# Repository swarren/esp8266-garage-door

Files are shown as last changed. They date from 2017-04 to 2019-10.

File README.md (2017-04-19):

# ESP8266 Internet Garage Door Opener

This repo contains all the design files relate to the ESP8266-based garage
door opener project I recently created. My basic requirements were:

- Be functonal and deployed as quickly as possible, rather than being as clean
and well-engineered as possible.

- Not interfere with the electronics of my existing manual-switch-triggered
opener.

Quick list of features/parts:

- ESP8266 WiFi SoC for the Internet connection. NodeMCU board.

- Arduino-based software stack.

- HTTP/HTML-based user interface.

- WiFi credentials entered at "run-time" using a web browser and saved to
flash, rather than being hard-coded into the application code.

- PCB created in Kicad to mount the ESP8266 and connectors.

- Standalone commercial relay board to trigger the door opener.

- HC-SR04 sensors used to detect whether the door is open or closed.

- HC-SR04 wall mounts designed using OpenSCAD and 3D-printed.

Look on my blog at http://rabbithole.wwwdotorg.org for more details.

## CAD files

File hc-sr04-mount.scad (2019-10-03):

/*
 * Copyright (c) 2017, Stephen Warren
 *
 * Permission is hereby granted, free of charge, to any person obtaining a
 * copy of this software and associated documentation files (the "Software"),
 * to deal in the Software without restriction, including without limitation
 * the rights to use, copy, modify, merge, publish, distribute, sublicense,
 * and/or sell copies of the Software, and to permit persons to whom the
 * Software is furnished to do so, subject to the following conditions:
 *
 * The above copyright notice and this permission notice shall be included in
 * all copies or substantial portions of the Software.
 *
 * THE SOFTWARE IS PROVIDED "AS IS", WITHOUT WARRANTY OF ANY KIND, EXPRESS OR
 * IMPLIED, INCLUDING BUT NOT LIMITED TO THE WARRANTIES OF MERCHANTABILITY,
 * FITNESS FOR A PARTICULAR PURPOSE AND NONINFRINGEMENT.  IN NO EVENT SHALL
 * THE AUTHORS OR COPYRIGHT HOLDERS BE LIABLE FOR ANY CLAIM, DAMAGES OR OTHER
 * LIABILITY, WHETHER IN AN ACTION OF CONTRACT, TORT OR OTHERWISE, ARISING
 * FROM, OUT OF OR IN CONNECTION WITH THE SOFTWARE OR THE USE OR OTHER
 * DEALINGS IN THE SOFTWARE.
 */

$fn = 30;

pcb_w = 45 + 1.5;
pcb_h = 20 + 2;
wall_thick = 3;
horn_r = 15.75 / 2;
horn_r_slop = 0.75;
horn_space = 41.5 - (2 * horn_r);
supp_h = 3.5;
supp_l = 7;
mount_depth = wall_thick + supp_h + 9;
flange_l = 10 + wall_thick;
clip_thick = 2;
clip_interior = 9.5;
clip_wide = 9;
clip_depth = 14;

module corner_dist(w, h) {
    translate([-w / 2, -h / 2, 0])
        rotate(0) children();
    translate([-w / 2,  h / 2, 0])
        rotate(270) children();
    translate([ w / 2, -h / 2, 0])
        rotate(90) children();
    translate([ w / 2,  h / 2, 0])
        rotate(180) children();
}

module hc_sr04_mount() {
    // Front face plate, with cut-outs for horns
    base_w = pcb_w + (2 * wall_thick);
    base_h = pcb_h;
    difference() {
        cube([base_w, base_h, wall_thick], center=true);
        translate([-horn_space / 2, 0, 0])
            cylinder(r=horn_r + horn_r_slop, h=(2 * wall_thick), center=true);
        translate([ horn_space / 2, 0, 0])
            cylinder(r=horn_r + horn_r_slop, h=(2 * wall_thick), center=true);
    }

    // Side walls
    wall_x_xlat = (base_w - wall_thick) / 2;
    translate([-wall_x_xlat, 0, (mount_depth - wall_thick) / 2])
        cube([wall_thick, pcb_h, mount_depth], center=true);
    translate([ wall_x_xlat, 0, (mount_depth - wall_thick) / 2])
        cube([wall_thick, pcb_h, mount_depth], center=true);

    // Corner supports
    corner_dist(w=pcb_w, h=pcb_h) {
        translate([0, 0, wall_thick / 2])
            linear_extrude(height=supp_h)
            polygon([[0, 0], [supp_l, 0], [0, supp_l]]);
    }
}

module hc_sr04_flange_a() {
    translate([0, 0, (mount_depth - wall_thick) / 2])
        cube([wall_thick, pcb_h, mount_depth], center=true);
    translate([(flange_l - wall_thick) / 2, 0, 0])
        cube([flange_l, pcb_h, wall_thick], center=true);
}

module hc_sr04_flange_b() {
    translate([0, 0, (mount_depth - wall_thick) / 2])
        cube([wall_thick, pcb_h, mount_depth], center=true);
    translate([(flange_l - wall_thick) / 2, (pcb_h - wall_thick) / 2, (mount_depth - wall_thick)/ 2])
        cube([flange_l, wall_thick, mount_depth], center=true);
}

module hc_sr04_flange_clip() {
    cube([clip_thick, clip_depth + clip_thick, clip_wide], center=true);
    translate([clip_interior + clip_thick, 0, 0])
        cube([clip_thick, clip_depth + clip_thick, clip_wide], center=true);
    translate([(clip_interior + clip_thick) / 2, clip_depth / 2, 0])
        cube([clip_interior + (2 * clip_thick), clip_thick, clip_wide], center=true);
}

hc_sr04_mount();

translate([ ((pcb_w / 2) + (4 * wall_thick)), 0, 0]) hc_sr04_flange_a();
//translate([-((pcb_w / 2) + (4 * wall_thick)), 0, 0]) rotate(180) hc_sr04_flange_a();

//translate([ ((pcb_w / 2) + (4 * wall_thick)), 0, 0]) hc_sr04_flange_b();
translate([-((pcb_w / 2) + (4 * wall_thick)), 0, 0]) rotate(180) hc_sr04_flange_b();

translate([0, -25, 0]) hc_sr04_flange_clip();

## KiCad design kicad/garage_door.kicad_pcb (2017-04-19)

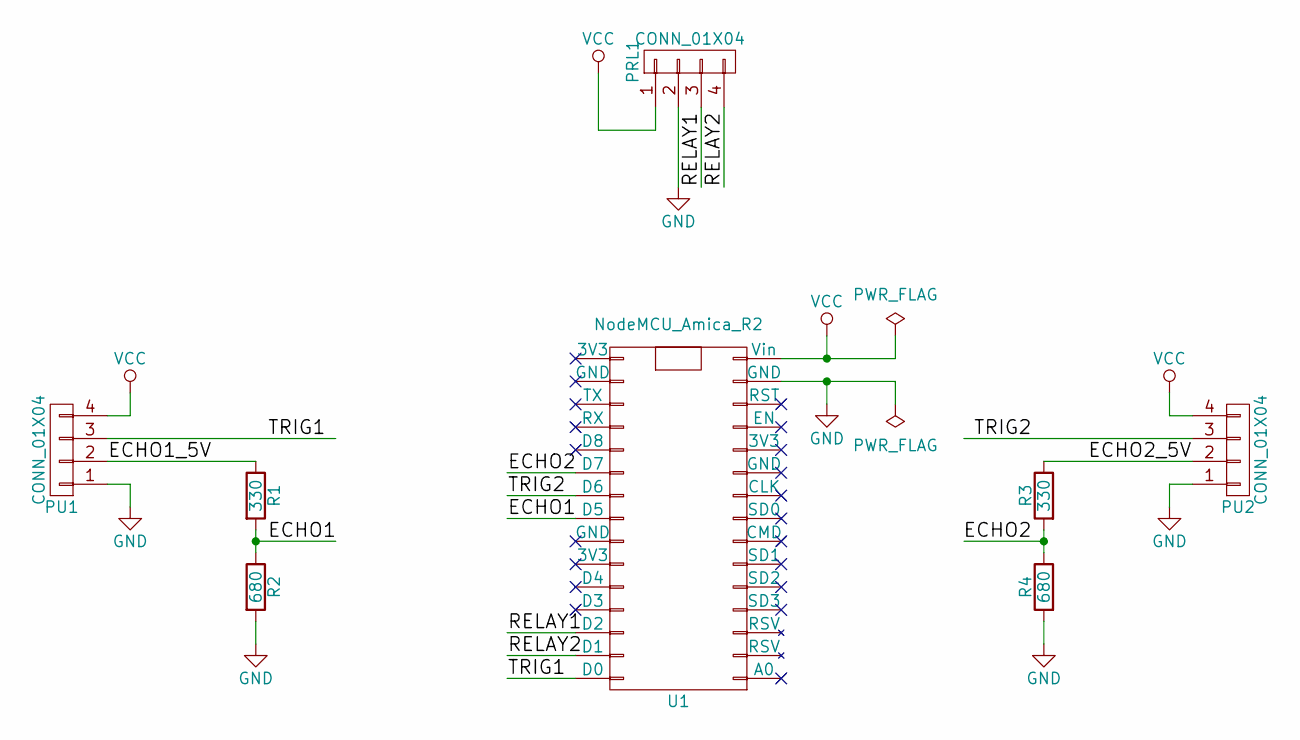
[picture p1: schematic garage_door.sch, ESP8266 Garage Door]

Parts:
PRL1: CONN_01X04; Pin_Header_Angled_1x04_Pitch2.54mm
PU1, PU2: CONN_01X04; Pin_Header_Angled_1x04_Pitch2.54mm
R1, R3: 330; R_Axial_DIN0207_L6.3mm_D2.5mm_P10.16mm_Horizontal
R2, R4: 680; R_Axial_DIN0207_L6.3mm_D2.5mm_P10.16mm_Horizontal
U1: NodeMCU_Amica_R2

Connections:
/ECHO1: R1.2, R2.1, U1.23 (D5)
/ECHO1_5V: PU1.2, R1.1
/ECHO2: R3.2, R4.1, U1.21 (D7)
/ECHO2_5V: PU2.2, R3.1
/RELAY1: PRL1.3, U1.28 (D2)
/RELAY2: PRL1.4, U1.29 (D1)
/TRIG1: PU1.3, U1.30 (D0)
/TRIG2: PU2.3, U1.22 (D6)
GND: PRL1.2, PU1.1, PU2.1, R2.2, R4.2, U1.14 (GND)
VCC: PRL1.1, PU1.4, PU2.4, U1.15 (Vin)

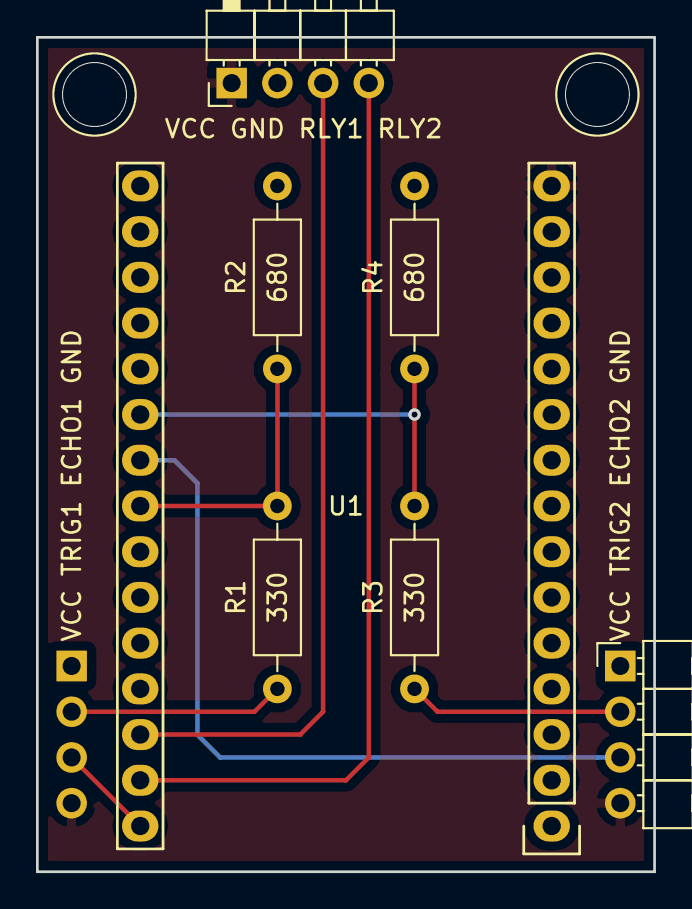
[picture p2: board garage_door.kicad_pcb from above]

Board: 2 copper layers, 34.3 x 46.4 mm, 8 parts (1 on the bottom side), 10 nets.

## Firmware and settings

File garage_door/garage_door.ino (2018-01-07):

/*
 * Copyright (c) 2017, Stephen Warren
 *
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
 * THE SOFTWARE IS PROVIDED "AS IS", WITHOUT WARRANTY OF ANY KIND, EXPRESS OR
 * IMPLIED, INCLUDING BUT NOT LIMITED TO THE WARRANTIES OF MERCHANTABILITY,
 * FITNESS FOR A PARTICULAR PURPOSE AND NONINFRINGEMENT.  IN NO EVENT SHALL
 * THE AUTHORS OR COPYRIGHT HOLDERS BE LIABLE FOR ANY CLAIM, DAMAGES OR OTHER
 * LIABILITY, WHETHER IN AN ACTION OF CONTRACT, TORT OR OTHERWISE, ARISING
 * FROM, OUT OF OR IN CONNECTION WITH THE SOFTWARE OR THE USE OR OTHER
 * DEALINGS IN THE SOFTWARE.
 */
 
#include <math.h>
#include <FS.h>
#include <ESP8266HTTPUpdateServer.h>
#include <ESP8266mDNS.h>
#include <ESP8266LLMNR.h>
#include <ESP8266WebServer.h>
#include <ESP8266WiFi.h>
#include "ESPAsyncTCP.h"

// Development on Adafruit Huzzah
#if 1
#define DEVID "-dev"
#define PIN_BTN 0
#if 1
#define DOOR0_NAME "Dev Door"
#define PIN_DOOR_0 5
#define PIN_ULTRA_TRIG_0 16
#define PIN_ULTRA_ECHO_0 4
#endif
#if 1
#define DOOR1_NAME "Second Door"
#define PIN_DOOR_1 14
#define PIN_ULTRA_TRIG_1 12
#define PIN_ULTRA_ECHO_1 13
#endif
#endif

// Production for main garage on NodeMCU; rev 1 PCB
#if 0
#define DEVID "-main"
#define PIN_BTN 0
#define DOOR0_NAME "Stephen's Door"
#define PIN_DOOR_0 16
#define PIN_ULTRA_TRIG_0 5
#define PIN_ULTRA_ECHO_0 4
#define DOOR1_NAME "Tina's Door"
#define PIN_DOOR_1 14
#define PIN_ULTRA_TRIG_1 12
#define PIN_ULTRA_ECHO_1 13
#endif

// Production for main garage on NodeMCU; rev 2 PCB
#if 0
#define DEVID "-main"
#define PIN_BTN 0
#define DOOR0_NAME "Stephen's Door"
#define PIN_DOOR_0 4
#define PIN_ULTRA_TRIG_0 16
#define PIN_ULTRA_ECHO_0 14
#define DOOR1_NAME "Tina's Door"
#define PIN_DOOR_1 5
#define PIN_ULTRA_TRIG_1 12
#define PIN_ULTRA_ECHO_1 13
#endif

// Production for third garage on NodeMCU; rev 1 PCB (2nd door pins)
#if 0
#define DEVID "-third"
#define PIN_BTN 0
#define DOOR0_NAME "Third Garage"
#define PIN_DOOR_0 14
#define PIN_ULTRA_TRIG_0 12
#define PIN_ULTRA_ECHO_0 13
#define SHORT_ECHO
#endif

#ifdef SHORT_ECHO
#define CLOSED_MIN_ECHO_TIME 500 /* us */
#else
#define CLOSED_MIN_ECHO_TIME \
  (1000000 /* s->us */ * 2 /* there and back */ * 0.3 /* meters */ / \
    343 /* sound_speed_meters_per_sec */)
#endif

#if defined(PIN_ULTRA_TRIG_0) || defined(PIN_ULTRA_TRIG_1)
#define DEBUG_ULTRA 0

class UltraEcho {
public:
  UltraEcho(int pin) :
    m_pin(pin),
    m_wait_for_echo_start(true)
  {
  }

  void pre_trigger(void) {
    m_wait_for_echo_start = true;
  }

  bool is_closed(void) {
    return __builtin_popcount(m_closed_hist & 0xff) >= 6;
  }

  String history_string(void) {
    int hist_bits = sizeof(m_closed_hist) * 8;
    char s[hist_bits + 1];
    for (int i = 0; i < hist_bits; i++)
      s[i] = (m_closed_hist & (1ULL << (hist_bits - i - 1))) ? '*' : '-';
    s[hist_bits] = 0;
    return s;
  }

  void isr_echo() {
    unsigned long t = micros();
    int val = digitalRead(m_pin);
#if DEBUG_ULTRA
    Serial.printf("Echo pin %d val %d waiting %d at %lu\n", m_pin, val, (int)m_wait_for_echo_start, t);
#endif
    if (m_wait_for_echo_start && val) {
#if DEBUG_ULTRA
      Serial.printf("Echo starts...\n");
#endif
      m_ts_echo_start = t;
      m_wait_for_echo_start = false;
    } else if (!m_wait_for_echo_start && !val) {
#if DEBUG_ULTRA
      Serial.printf("Echo done...\n");
#endif
      m_echo_time = t - m_ts_echo_start;
#if DEBUG_ULTRA
      Serial.printf("Echo pin %d time %d us\n", m_pin, m_echo_time);
#endif
      bool closed = (m_echo_time < CLOSED_MIN_ECHO_TIME);
#if DEBUG_ULTRA
      Serial.printf("Closed? %d\n", (int)closed);
#endif
      m_closed_hist <<= 1;
      m_closed_hist |= !!closed;
#if DEBUG_ULTRA
      Serial.printf("Closed hist: 0x%x ?%d\n", m_closed_hist, !!is_closed());
#endif
    }
  }

private:
  int m_pin;
  bool m_wait_for_echo_start;
  unsigned long m_ts_echo_start;
  unsigned long m_echo_time;
  unsigned int m_closed_hist;
};
#endif

enum RelayControllerState {
  RC_STATE_IDLE,
  RC_STATE_HIGH_TIMER,
  RC_STATE_LOW_TIMER,
};

class RelayController {
public:
  RelayController(int pin) :
    m_pin(pin),
    m_trig_count(0),
    m_state(RC_STATE_IDLE),
    m_state_start(0) {
  }

  void iter() {
    switch (m_state) {
    case RC_STATE_HIGH_TIMER:
      if ((millis() - m_state_start) < 500)
        break;
      m_state = RC_STATE_LOW_TIMER;
      m_state_start = millis();
      digitalWrite(m_pin, LOW);
      break;
    case RC_STATE_LOW_TIMER:
      if ((millis() - m_state_start) < 500)
        break;
      m_state = RC_STATE_IDLE;
      // deliberate fall-through
    case RC_STATE_IDLE:
    default:
      if (!m_trig_count)
        break;
      m_trig_count--;
      m_state = RC_STATE_HIGH_TIMER;
      m_state_start = millis();
      digitalWrite(m_pin, HIGH);
      break;
    }
  }

  void trigger() {
    m_trig_count++;
  }

private:
  int m_pin;
  int m_trig_count;
  enum RelayControllerState m_state;
  unsigned long m_state_start;
};

#define DEBUG_SMTP 1

enum SMTPClientState {
  SMTP_STATE_IDLE,
  SMTP_STATE_WAIT_CONNECT,
  SMTP_STATE_WAIT_SIGNON,
  SMTP_STATE_WAIT_FEATURES,
  SMTP_STATE_WAIT_MAIL_FROM_OK,
  SMTP_STATE_WAIT_RCPT_TO_OK,
  SMTP_STATE_WAIT_DATA_RESPONSE,
  SMTP_STATE_WAIT_END_DATA_RESPONSE,
  SMTP_STATE_WAIT_QUIT_RESPONSE,
  SMTP_STATE_WAIT_CLOSED,
};

class LineBuf {
public:
  LineBuf(void) : m_filled(0) {
  }

  void clear(void) {
    m_filled = 0;
  }

  size_t append(void *data, size_t len) {
    size_t space = sizeof(m_data) - m_filled - 1;
    size_t consumed = (space < len) ? space : len;
    memcpy(&m_data[m_filled], data, consumed);
    m_filled += consumed;
    m_data[m_filled] = '\0';
    return consumed;
  }

  char *get_line(size_t *token) {
    char *eol = strstr(m_data, "\r\n");
    if (!eol) {
      *token = 0;
      return NULL;
    }
    *eol = '\0';
    *token = eol - m_data + 2;
#if DEBUG_SMTP
    Serial.printf("SMTP << %s\n", m_data);
#endif
    return m_data;
  }

  void consume_line(size_t token) {
    memcpy(m_data, &m_data[token], m_filled - token);
    m_filled -= token;
  }

private:
  char m_data[128];
  size_t m_filled;
};

class SMTPClient {
public:
  SMTPClient() :
    m_state(SMTP_STATE_IDLE),
    m_data_door_name(NULL),
    m_data_closed(false),
    m_client(NULL),
    m_ibuf()
  {
  }

  bool is_busy() {
    return m_state != SMTP_STATE_IDLE;
  }

  bool start_email(const char *door_name, bool closed) {
#if DEBUG_SMTP
    Serial.printf("SMTP (%d) start_email()\n", m_state);
#endif
    if (m_state != SMTP_STATE_IDLE) {
#if DEBUG_SMTP
      Serial.printf("SMTP skip start due to active\n");
#endif
      return false;
    }
    m_data_door_name = door_name;
    m_data_closed = closed;
    m_ibuf.clear();

    m_client = new AsyncClient();
    m_client->onTimeout(_on_timeout, this);
    m_client->onConnect(_on_connect, this);
    m_client->onDisconnect(_on_disconnect, this);
    m_client->onData(_on_data, this);

    bool in_progress = m_client->connect("192.168.63.2", 25);
    if (!in_progress) {
#if DEBUG_SMTP
      Serial.printf("SMTP skip start due to connect() failed\n");
#endif
      return false;
    }
    set_state(SMTP_STATE_WAIT_CONNECT);
    return true;
  }

  void iter(void) {
    unsigned long timeout;
    switch (m_state) {
    case SMTP_STATE_IDLE:
      return;
    case SMTP_STATE_WAIT_SIGNON:
      timeout = 10000;
      break;
    default:
      timeout = 2000;
      break;
    }

    unsigned long t = millis();
    if ((t - m_state_time) < timeout)
      return;

#if DEBUG_SMTP
    Serial.printf("SMTP (%d) iter timeout (s:%lu +%lu t:%lu)\n", m_state, m_state_time, timeout, t);
#endif
    close_connection();
  }

private:
  SMTPClientState m_state;
  unsigned long m_state_time;
  const char *m_data_door_name;
  bool m_data_closed;
  AsyncClient *m_client;
  LineBuf m_ibuf;

  static void _on_timeout(void *obj, AsyncClient* c, uint32_t time) {
    SMTPClient *scl = (SMTPClient *)obj;
    scl->on_timeout();
  }
  static void _on_connect(void *obj, AsyncClient* c) {
    SMTPClient *scl = (SMTPClient *)obj;
    scl->on_connect();
  }
  static void _on_disconnect(void *obj, AsyncClient* c) {
    SMTPClient *scl = (SMTPClient *)obj;
    scl->on_disconnect();
  }
  static void _on_data(void *obj, AsyncClient* c, void *data, size_t len) {
    SMTPClient *scl = (SMTPClient *)obj;
    scl->on_data(data, len);
  }

  void set_state(SMTPClientState new_state) {
#if DEBUG_SMTP
    if (new_state != m_state)
      Serial.printf("SMTP state -> %d\n", new_state);
#endif
    m_state = new_state;
    m_state_time = millis();
  }

  void close_connection() {
    switch (m_state) {
    case SMTP_STATE_IDLE:
    case SMTP_STATE_WAIT_CLOSED:
      return;
    default:
      break;
    }
    m_client->close();
    set_state(SMTP_STATE_WAIT_CLOSED);
  }

  void on_timeout() {
#if DEBUG_SMTP
    Serial.printf("SMTP (%d) on_timeout()\n", m_state);
#endif
    close_connection();
  }

  void on_connect() {
#if DEBUG_SMTP
    Serial.printf("SMTP (%d) on_connected()\n", m_state);
#endif
    switch (m_state) {
    case SMTP_STATE_WAIT_CONNECT:
      set_state(SMTP_STATE_WAIT_SIGNON);
      break;
    default:
#if DEBUG_SMTP
      Serial.printf("SMTP on_connect(): disconnect due to bad state\n");
#endif
      close_connection();
      break;
    }
  }

  void on_disconnect() {
#if DEBUG_SMTP
    Serial.printf("SMTP (%d) on_disconnect()\n", m_state);
#endif
    m_client->abort();
    delete m_client;
    m_client = NULL;
    set_state(SMTP_STATE_IDLE);
  }

  void on_data(void *data, size_t len) {
#if DEBUG_SMTP
    Serial.printf("SMTP (%d) on_data() RX (%d)\n", m_state, len);
#endif
    while (len) {
      size_t consumed = m_ibuf.append(data, len);
      if (!consumed) {
#if DEBUG_SMTP
        Serial.printf("SMTP on_data(): disconnect due to !consumed\n");
#endif
        close_connection();
        return;
      }
      data += consumed;
      len -= consumed;
      do {
        size_t token;
        char *line = m_ibuf.get_line(&token);
        if (!line)
          break;
        switch (m_state) {
        case SMTP_STATE_WAIT_SIGNON:
          on_data_wait_signon(line);
          break;
        case SMTP_STATE_WAIT_FEATURES:
          on_data_wait_features(line);
          break;
        case SMTP_STATE_WAIT_MAIL_FROM_OK:
          on_data_wait_mail_from_ok(line);
          break;
        case SMTP_STATE_WAIT_RCPT_TO_OK:
          on_data_wait_rcpt_to_ok(line);
          break;
        case SMTP_STATE_WAIT_DATA_RESPONSE:
          on_data_wait_data_reponse(line);
          break;
        case SMTP_STATE_WAIT_END_DATA_RESPONSE:
          on_data_wait_end_data_response(line);
          break;
        case SMTP_STATE_WAIT_QUIT_RESPONSE:
          on_data_wait_quit_response(line);
          break;
        default:
#if DEBUG_SMTP
          Serial.printf("SMTP on_data(): disconnect due to bad state\n");
#endif
          close_connection();
          break;
        }
        m_ibuf.consume_line(token);
      } while (true);
    }
  }

  void send(const char *line) {
#if DEBUG_SMTP
    Serial.printf("SMTP >> %s", line);
    /*
     * This should never happen, since SMTP is a synchronous protocol, and the
     * far-end TCP stack should ACK whatever we last sent as part of sending
     * its response.
     */
    if (!m_client->canSend())
        Serial.print("ERROR: SMTP SEND WHEN !canSend()\n");
#endif
    m_client->write(line);
  }

  void on_data_wait_signon(char *line) {
    bool ok = !strncmp(line, "220 ", 4);
    if (!ok) {
#if DEBUG_SMTP
      Serial.printf("SMTP on_data_wait_signon(): disconnect due to !ok\n");
#endif
      close_connection();
      return;
    }
    send("EHLO garage-door" DEVID ".local\r\n");
    set_state(SMTP_STATE_WAIT_FEATURES);
  }

  void on_data_wait_features(char *line) {
    bool cont = !strncmp(line, "250-", 4);
    bool last = !strncmp(line, "250 ", 4);
    if (!cont && !last) {
#if DEBUG_SMTP
      Serial.printf("SMTP on_data_wait_features(): disconnect due to !cont && !last\n");
#endif
      close_connection();
      return;
    }
    if (!last)
      return;
    send("MAIL FROM: <garage-door" DEVID "@wwwdotorg.org>\r\n");
    set_state(SMTP_STATE_WAIT_MAIL_FROM_OK);
  }

  void on_data_wait_mail_from_ok(char *line) {
    bool ok = !strncmp(line, "250 ", 4);
    if (!ok) {
#if DEBUG_SMTP
      Serial.printf("SMTP on_data_wait_mail_from_ok(): disconnect due to !ok\n");
#endif
      close_connection();
      return;
    }
    send("RCPT TO: <s-garage-door" DEVID "@wwwdotorg.org>\r\n");
    set_state(SMTP_STATE_WAIT_RCPT_TO_OK);
  }

  void on_data_wait_rcpt_to_ok(char *line) {
    bool ok = !strncmp(line, "250 ", 4);
    if (!ok) {
#if DEBUG_SMTP
      Serial.printf("SMTP on_data_wait_rcpt_to_ok(): disconnect due to !ok\n");
#endif
      close_connection();
      return;
    }
    send("DATA\r\n");
    set_state(SMTP_STATE_WAIT_DATA_RESPONSE);
  }

  void on_data_wait_data_reponse(char *line) {
    bool ok = !strncmp(line, "354 ", 4);
    if (!ok) {
#if DEBUG_SMTP
      Serial.printf("SMTP on_data_wait_data_reponse(): disconnect due to !ok\n");
#endif
      close_connection();
      return;
    }
    char msg[256];
    snprintf(msg, sizeof(msg),
      "From: <garage-door" DEVID "@wwwdotorg.org>\r\n"
      "To: <s-garage-door" DEVID "@wwwdotorg.org>\r\n"
      "Subject: %s now %s.\r\n"
      ".\r\n",
      m_data_door_name, m_data_closed ? "CLOSED" : "OPEN");
    send(msg);
    set_state(SMTP_STATE_WAIT_END_DATA_RESPONSE);
  }

  void on_data_wait_end_data_response(char *line) {
    bool ok = !strncmp(line, "250 ", 4);
    if (!ok) {
#if DEBUG_SMTP
      Serial.printf("SMTP on_data_wait_end_data_response(): disconnect due to !ok\n");
#endif
      close_connection();
      return;
    }
    send("QUIT\r\n");
    set_state(SMTP_STATE_WAIT_QUIT_RESPONSE);
  }

  void on_data_wait_quit_response(char *line) {
    bool ok = !strncmp(line, "221 ", 4);
    if (!ok) {
#if DEBUG_SMTP
      Serial.printf("SMTP on_data_wait_quit_response(): disconnect due to !ok\n");
#endif
      close_connection();
      return;
    }
#if DEBUG_SMTP
    Serial.printf("SMTP on_data_wait_quit_response(): disconnect due to quit response\n");
#endif
    close_connection();
  }
};
SMTPClient smtp_client;

struct SMTPQueueEntry {
  const char *door_name;
  bool closed;
};
template <int QLEN> class SMTPQueue {
public:
  SMTPQueue() :
    m_num_entries(0)
  {
  }

  void add(const char *door_name, bool closed) {
    if (m_num_entries == QLEN)
      return;
    m_entries[m_num_entries].door_name = door_name;
    m_entries[m_num_entries].closed = closed;
    m_num_entries++;
  }

  void iter() {
    if (!m_num_entries)
      return;
    if (smtp_client.is_busy())
        return;
    bool started = smtp_client.start_email(m_entries[0].door_name,
      m_entries[0].closed);
    if (!started)
      return;
    m_num_entries--;
    memcpy(m_entries, &m_entries[1], m_num_entries * sizeof(m_entries[0]));
  }

private:
  struct SMTPQueueEntry m_entries[QLEN];
  int m_num_entries;
};
SMTPQueue<4> smtp_queue;

static String ssid;
static String wifipw;
RelayController relay0(PIN_DOOR_0);
#ifdef PIN_DOOR_1
RelayController relay1(PIN_DOOR_1);
#endif
#ifdef PIN_ULTRA_TRIG_0
static UltraEcho ultra_echo_0(PIN_ULTRA_ECHO_0);
#endif
#ifdef PIN_ULTRA_TRIG_1
static UltraEcho ultra_echo_1(PIN_ULTRA_ECHO_1);
#endif
static ESP8266WebServer web_server(80);
static ESP8266HTTPUpdateServer http_updater;

#ifdef PIN_ULTRA_TRIG_0
void isr_ultra_echo_0() {
  ultra_echo_0.isr_echo();
}
#endif

#ifdef PIN_ULTRA_TRIG_1
void isr_ultra_echo_1() {
  ultra_echo_1.isr_echo();
}
#endif

bool web_client_is_sta() {
  return web_server.client().localIP() == WiFi.localIP();
}

bool web_client_is_ap() {
  return web_server.client().localIP() == WiFi.softAPIP();
}

bool str_isprint(String s) {
  for (int i = 0; i < s.length(); i++)
    if (!isprint(s[i]))
      return false;
  return true;
}

void handle_http_not_found() {
  web_server.send(404, "text/plain", "Not Found");
}

const char html_unconfigured_ap_root[] = { "\
<html\
<head>\
<title>Set Configuration</title>\
</head>\
<body>\
<p>Please set configuration:</p>\
<form method=\"POST\" action=\"/set_config\">\
WiFi Network (SSID): <input type=\"text\" name=\"SSID\"/><br/>\
WiFi Password: <input type=\"text\" name=\"WIFIPW\"/><br/>\
<input type=\"submit\" value=\"Configure\"/>\
</form>\
</body>\
</html>\
"
};

void handle_http_unconfigured_ap_get_root() {
  web_server.send(200, "text/html", html_unconfigured_ap_root);
}

const char html_unconfigured_sta_root[] = { "\
<html\
<head>\
<title>Save Configuration</title>\
</head>\
<body>\
<p>Please save configuration:</p>\
<form method=\"POST\" action=\"/save_config\">\
<input type=\"submit\" value=\"Save\"/>\
</form>\
</body>\
</html>\
"
};

void handle_http_unconfigured_sta_get_root() {
  web_server.send(200, "text/html", html_unconfigured_sta_root);
}

void handle_http_unconfigured_get_root() {
  if (web_client_is_ap())
    handle_http_unconfigured_ap_get_root();
  else
    handle_http_unconfigured_sta_get_root();
}

void handle_http_unconfigured_ap_post_set_config() {
  if (!web_client_is_ap()) {
    web_server.send(409, "text/plain",
      "This URL may only be accessed from the access point WiFi network");
    return;
  }

  if (!web_server.hasArg("SSID")) {
    web_server.send(400, "text/plain", "SSID missing");
    return;
  }
  ssid = web_server.arg("SSID");
  if (!ssid.length()) {
    web_server.send(400, "text/plain", "SSID empty");
    return;
  }
  if (!str_isprint(ssid)) {
    web_server.send(400, "text/plain", "SSID invalid");
    return;
  }

  if (!web_server.hasArg("WIFIPW")) {
    web_server.send(400, "text/plain", "WiFi password missing");
    return;
  }
  wifipw = web_server.arg("WIFIPW");
  if (!wifipw.length()) {
    web_server.send(400, "text/plain", "WiFi password empty");
    return;
  }
  if (!str_isprint(wifipw)) {
    web_server.send(400, "text/plain", "WiFi password invalid");
    return;
  }

  WiFi.mode(WIFI_AP_STA);
  WiFi.begin(ssid.c_str(), wifipw.c_str());
  WiFi.setAutoConnect(true);
  WiFi.setAutoReconnect(true);

  web_server.send(200, "text/plain", "Station network initiated");
}

void handle_http_unconfigured_sta_post_save_config() {
  if (!web_client_is_sta()) {
    web_server.send(409, "text/plain",
      "This URL may only be accessed from the station WiFi network");
    return;
  }

  File f = SPIFFS.open("/config.txt", "w");
  f.println(ssid);
  f.println(wifipw);
  f.flush();
  f.close();
  SPIFFS.end();

  web_server.send(200, "text/plain", "Configuration Saved! Rebooting...");
  delay(1 * 1000);
  ESP.restart();
}

const char html_configured_sta_get_root[] = { "\
<html\
<head>\
<title>Door Control</title>\
</head>\
<body>"
#ifdef DOOR0_NAME
"<form method=\"POST\" action=\"/\">\
<input type=\"hidden\" name=\"door\" value=\"0\"/>\
<input type=\"submit\" value=\"Activate " DOOR0_NAME "\"/>\
</form>"
#ifdef PIN_ULTRA_TRIG_0
"State: STATE0<br/>"
"History: HIST0<br/>"
#endif
"<hr/>"
#endif
#ifdef DOOR1_NAME
"<form method=\"POST\" action=\"/\">\
<input type=\"hidden\" name=\"door\" value=\"1\"/>\
<input type=\"submit\" value=\"Activate " DOOR1_NAME "\"/>\
</form>"
#ifdef PIN_ULTRA_TRIG_1
"State: STATE1<br/>"
"History: HIST1<br/>"
#endif
"<hr/>"
#endif
"</body>\
</html>\
"
};
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
void loop() {
  web_server.handleClient();

  static bool printed_ap_ip;
  if (!printed_ap_ip) {
    Serial.print("AP IP: ");
    Serial.println(WiFi.softAPIP().toString());
    printed_ap_ip = true;
  }

  static bool prev_sta_connected;
  bool new_sta_connected = WiFi.isConnected();
  if (prev_sta_connected != new_sta_connected) {
    prev_sta_connected = new_sta_connected;
    Serial.print("STA connected? ");
    Serial.print(prev_sta_connected);
    Serial.print("; IP=");
    Serial.println(WiFi.localIP().toString());
  }

  static unsigned long btn_pressed_time;
  if (btn_pressed_time) {
    if (digitalRead(PIN_BTN)) {
      btn_pressed_time = 0;
    } else {
      if ((millis() - btn_pressed_time) > (10 * 1000)) {
        Serial.println("Clearing configuration...");
        SPIFFS.format();
        Serial.println("Rebooting...");
        ESP.restart();
      }
    }
  } else {
    if (!digitalRead(PIN_BTN))
      btn_pressed_time = millis();
  }

#if DEBUG_SMTP
  if (Serial.read() == 'e') {
    Serial.printf("Sending 2 test emails\n");
    smtp_queue.add("EmailTest1", false);
    smtp_queue.add("EmailTest2", false);
  }
#endif

#ifdef PIN_ULTRA_TRIG_0
  {
    static bool door0_last_closed = true;
    bool door0_closed = ultra_echo_0.is_closed();
    if (door0_closed != door0_last_closed) {
      door0_last_closed = door0_closed;
      smtp_queue.add(DOOR0_NAME, door0_closed);
    }
  }
#endif
#ifdef PIN_ULTRA_TRIG_1
  {
    static bool door1_last_closed = true;
    bool door1_closed = ultra_echo_1.is_closed();
    if (door1_closed != door1_last_closed) {
      door1_last_closed = door1_closed;
      smtp_queue.add(DOOR1_NAME, door1_closed);
    }
  }
#endif
  if (new_sta_connected) {
    smtp_client.iter();
    smtp_queue.iter();
  }
  relay0.iter();
#ifdef PIN_DOOR_1
  relay1.iter();
#endif

#if defined(PIN_ULTRA_TRIG_0) || defined(PIN_ULTRA_TRIG_1)
  static bool ultra_trigger_active;
  static unsigned long ultra_state_start;
  unsigned long t = millis();
  unsigned long ultra_state_elapsed = t - ultra_state_start;
  unsigned long ultra_max_state_time =
    ultra_trigger_active ? 10 : 2500;
  if (ultra_state_elapsed > ultra_max_state_time) {
    ultra_state_start = t;
    ultra_trigger_active = !ultra_trigger_active;
    if (ultra_trigger_active) {
#ifdef PIN_ULTRA_TRIG_0
      ultra_echo_0.pre_trigger();
#endif
#ifdef PIN_ULTRA_TRIG_1
      ultra_echo_1.pre_trigger();
#endif
    }
#if DEBUG_ULTRA
    Serial.printf("t %lu trig %d\n", t, (int)ultra_trigger_active);
#endif
#ifdef PIN_ULTRA_TRIG_0
    digitalWrite(PIN_ULTRA_TRIG_0, ultra_trigger_active);
#endif
#ifdef PIN_ULTRA_TRIG_1
    digitalWrite(PIN_ULTRA_TRIG_1, ultra_trigger_active);
#endif
  }
#endif
}

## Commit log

2017-04-19 Initial version
    [garage_door.kicad_pcb, garage_door.sch, hc-sr04-mount.scad]
2017-04-25 Rev 2 PCB updates
    - Rev 2 PCB tested on main garage door; remove untested comment.
    - Deploy rev 1 PCB to third garage door; update its config stanza.
    Ultrasound sensor still needs physical wiring, but the SW is prepared.
    - Move Arduino code into a sub-dir with matching name so the IDE doesn't
    complain about the directory name:-/
    - Remove vi temp file, add .gitignore file for them.
    [garage_door.ino]
2017-05-11 Fix cut/paste mistake in license headers
    [hc-sr04-mount.scad]
2017-06-17 Control relays via a state machine
    This avoids synchronously blocking in the POST handler, which should
    improve responsiveness of the web server an IP stack in general
    immediately after a request to active a door.
    [garage_door.ino]
2018-01-03 Display sensor history in HTML
    This makes it easier to see what state the door is in, since each
    individual ping result can be seen.
2018-01-05 Send email when door opens/closes
    This is enough to work, but the code is pretty icky.
    TODO:
    - Get SMTP parameters via /setup URL rather than hard-coding them.
    - Share code between the many SMTP state; likely by creating an array
    of RX/TX lines and simply iterating over it.
    - Read SMTP spec to determine whether it's OK to hard-code the response
    codes or whether a variety of codes should be accepted.
    - Email body, e.g. ultrasound state history?
    - Any more debug spew needed?
    - Remove items from queue when send complete, not when send starts.
    - SMTP Authentication and SSL/TLS are explicit non-goals since I know that
    I have a local relay/smart server.
    - Explicit "I rebooted" email?
    - Elid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
    [garage_door.ino]
2018-01-06 SMTP reliability and consolidation
    - AsyncClient randomly fires onDisconnect() callbacks if it's re-used for
    multiple connections. Create/Destroy it for each transaction to avoid
    this.
    - This means that the AsyncClient callbacks must be set each time the
    AsyncClient is created. Using closures for this seems to leak memory.
    Use static _on_xxx() callback implementations to avoid this.
    - Consolidate common line waiting logic out of state-specific code into
    core code.
    - Vary timeouts per state, since e.g. the initial TCP connection could
    easily require more time than other operations (e.g. waking up ESP's
    WiFi connection, paging in the SMTP server on the host).
    - Add to the SMTP qu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
    [garage_door.ino]
2018-01-07 Fix third garage ultrasound echo time
    The ultrasound device placement is different on the third door, being
    aimed at the side of the door through a narrow gap. This yields very short
    positive ping times. Unfortunately, other material such as a rubber draft
    flap sometimes bend into the path of the ultrasound and creates false
    positive closed indications. To prevent this, only accept very close ping
    times for this door.
    [garage_door.ino]
2019-10-03 Fix OpenSCAD file copyright comment format
    [hc-sr04-mount.scad]
